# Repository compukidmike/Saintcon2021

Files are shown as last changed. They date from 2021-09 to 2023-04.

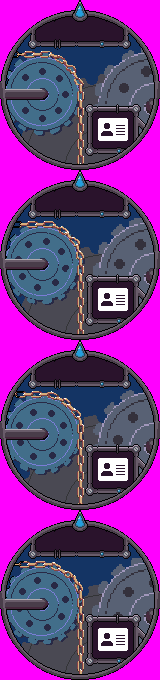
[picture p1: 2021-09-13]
Saintcon2021/ExternalFlash/menu.png

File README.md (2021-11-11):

# Saintcon2021

BadgeFrontUnlocked

This year's badge was created by compukidmike, Professor_Plum, and Sodium_Hydrogen. It's styled after a combination lock and the shackle actually opens!

BadgeFrontLocked

We tried something different for the front PCB. We used pcbbuy.com because they can do 2-color soldermask. It didn't turn out exactly like planned, but it was still a cool option that we'll probably use in the future.

One of the major features of the badge is NFC. The badge can read and write NFC tags, as well as emulate cards. This is used for sharing contact information, reading unlock tags, and trading items.

The main microcontroller is an ATSAME53J18A. The NFC controller is an ST25R95 and the LCD is actually round. The badge is composed of a stack of PCBs (4 boards thick, 5 boards total). Here's an exploded view of the badge:

Exploded
Inside

One of the big challenges was fitting parts under the screen. We've got the thickness of 2 boards (3.2mm) to fit everything. The LCD is 2.2mm thick, so that leaves 1mm for components. This made it extremely difficult to find parts, especially with the chip shortages this year.

## Firmware

### Compiling

You'll need to install ~~Atmel~~ Microchip Studio to compile the firmware. Once it's compiled, you can flash it to the badge with an SWD programmer, or follow the directions below to use the USB bootloader.

### Making a UF2 File

When you've compiled the firmware, Microchip Studio will create a bunch of files (likely in the Debug folder inside your project folder). You want the .hex file. You'll need to use a tool called uf2conv.py from https://github.com/microsoft/uf2 (it's in the utils folder). This python script will convert your hex file into a UF2 file that you can use to program your badge. Here's an example command: python .\uf2conv.py .\flash.bin -c -o .\flash.uf2

### Flashing

To re-flash your badge there is a USB bootloader. To activate it, move the power switch to USB and hold the button on the right side of the badge when you connect it to your computer. The screen should show some hardware tests and then it will connect to your computer as a mass storage device. Simply copy the new UF2 firmware file to the badge.

### External SPI Flash

The badge has an 8MB SPI flash chip that stores all the images. It can be reprogrammed via the bootloader, but it's a bit cumbersome. You'll need to use the makeFlash.py script in the ExternalFlash folder to create a binary file from the images. NOTE: The images will be placed in the binary one after the other aligned to 1024 byte boundaries. If you change the images, you'll need to update the list of image locations in flash.h

Once you've got the binary file, you need to convert it to a hex file. This can be done with with bin2hex.py script in the ExternalFlash folder. Here's an example command: python .\bin2hex.py .\flash.bin .\flash.hex

Finally, you need to convert this hex file into a UF2 file that the bootloader can use to reprogram the SPI flash. When using the uf2conv.py script, you'll need to add an offset parameter so that the bootloader knows this data is for the SPI flash. Here's an example command: python .\uf2conv.py .\flash.bin -c -b 0x4000000 -o .\flash.uf2

NOTE: When copying a UF2 file that reprograms the SPI flash, the badge will send an erase command to the SPI flash. This can take a while (30-60 seconds) and you will see an activity indicator on the screen. If this process takes too long, your computer may timeout on copying the file (the badge will change from "erasing" to "writing", but the LED will be pulsing slowly instead of blinking rapidly). If this happens, simply reset the badge into bootloader mode and copy the file again. This time the SPI flash will be empty and the erase command will be quick.

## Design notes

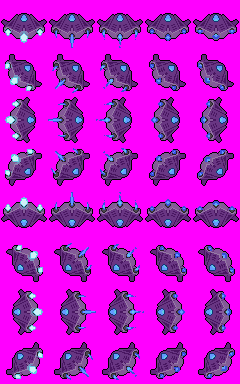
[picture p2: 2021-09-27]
Saintcon2021/ExternalFlash/ship.png

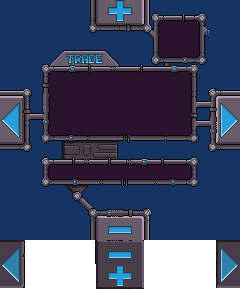
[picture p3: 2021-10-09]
Saintcon2021/ExternalFlash/trade.png

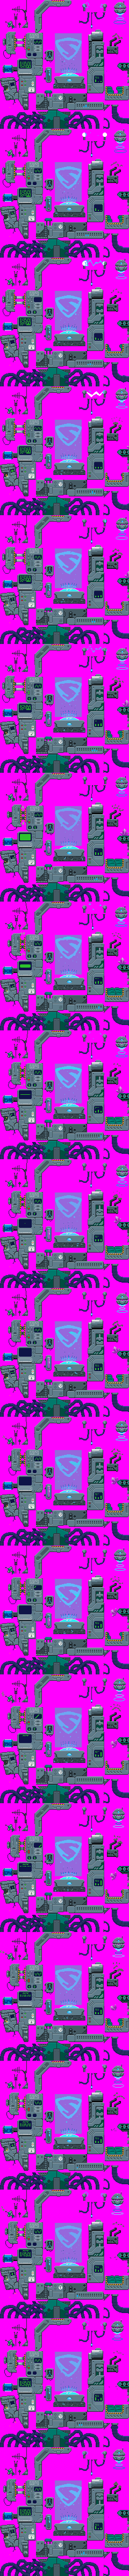
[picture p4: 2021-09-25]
Saintcon2021/ExternalFlash/machine.png

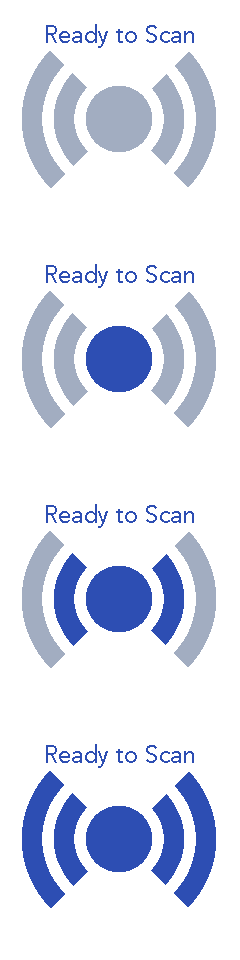
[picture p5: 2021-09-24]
Saintcon2021/ExternalFlash/nfc.png

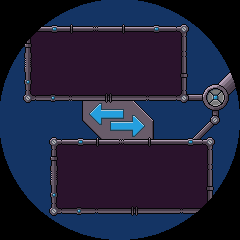
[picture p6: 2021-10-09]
Saintcon2021/ExternalFlash/trade2.png

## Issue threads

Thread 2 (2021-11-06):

Minibadge message collisions

kfeuz, 2021-11-06:
I have multiple hackers challenge minibadges which each have a little eeprom to store a message to be displayed by the main badge.  I changed the i2c address for each minibadge eeprom so that they don't collide and I can see each message start to be displayed.  However, each message clobber's the previous message as soon as it the code cycles to that address.  I propose adding a variable to track if the i2c address is displaying a message and if so wait for the appropriate delay before moving on to the next message. It looks like this was the plan all along but never got fully implemented (i.e. there is an if(true) statement right before checking the next minibadge address).  I can make the code change but I don't know how to build the code and how to flash the code after that.  Can you provide some guidance on that process or point me to the right resources to do so?

compukidmike, 2021-11-12:
Thanks for finding this bug and fixing the code!

Closed 2021-11-12.

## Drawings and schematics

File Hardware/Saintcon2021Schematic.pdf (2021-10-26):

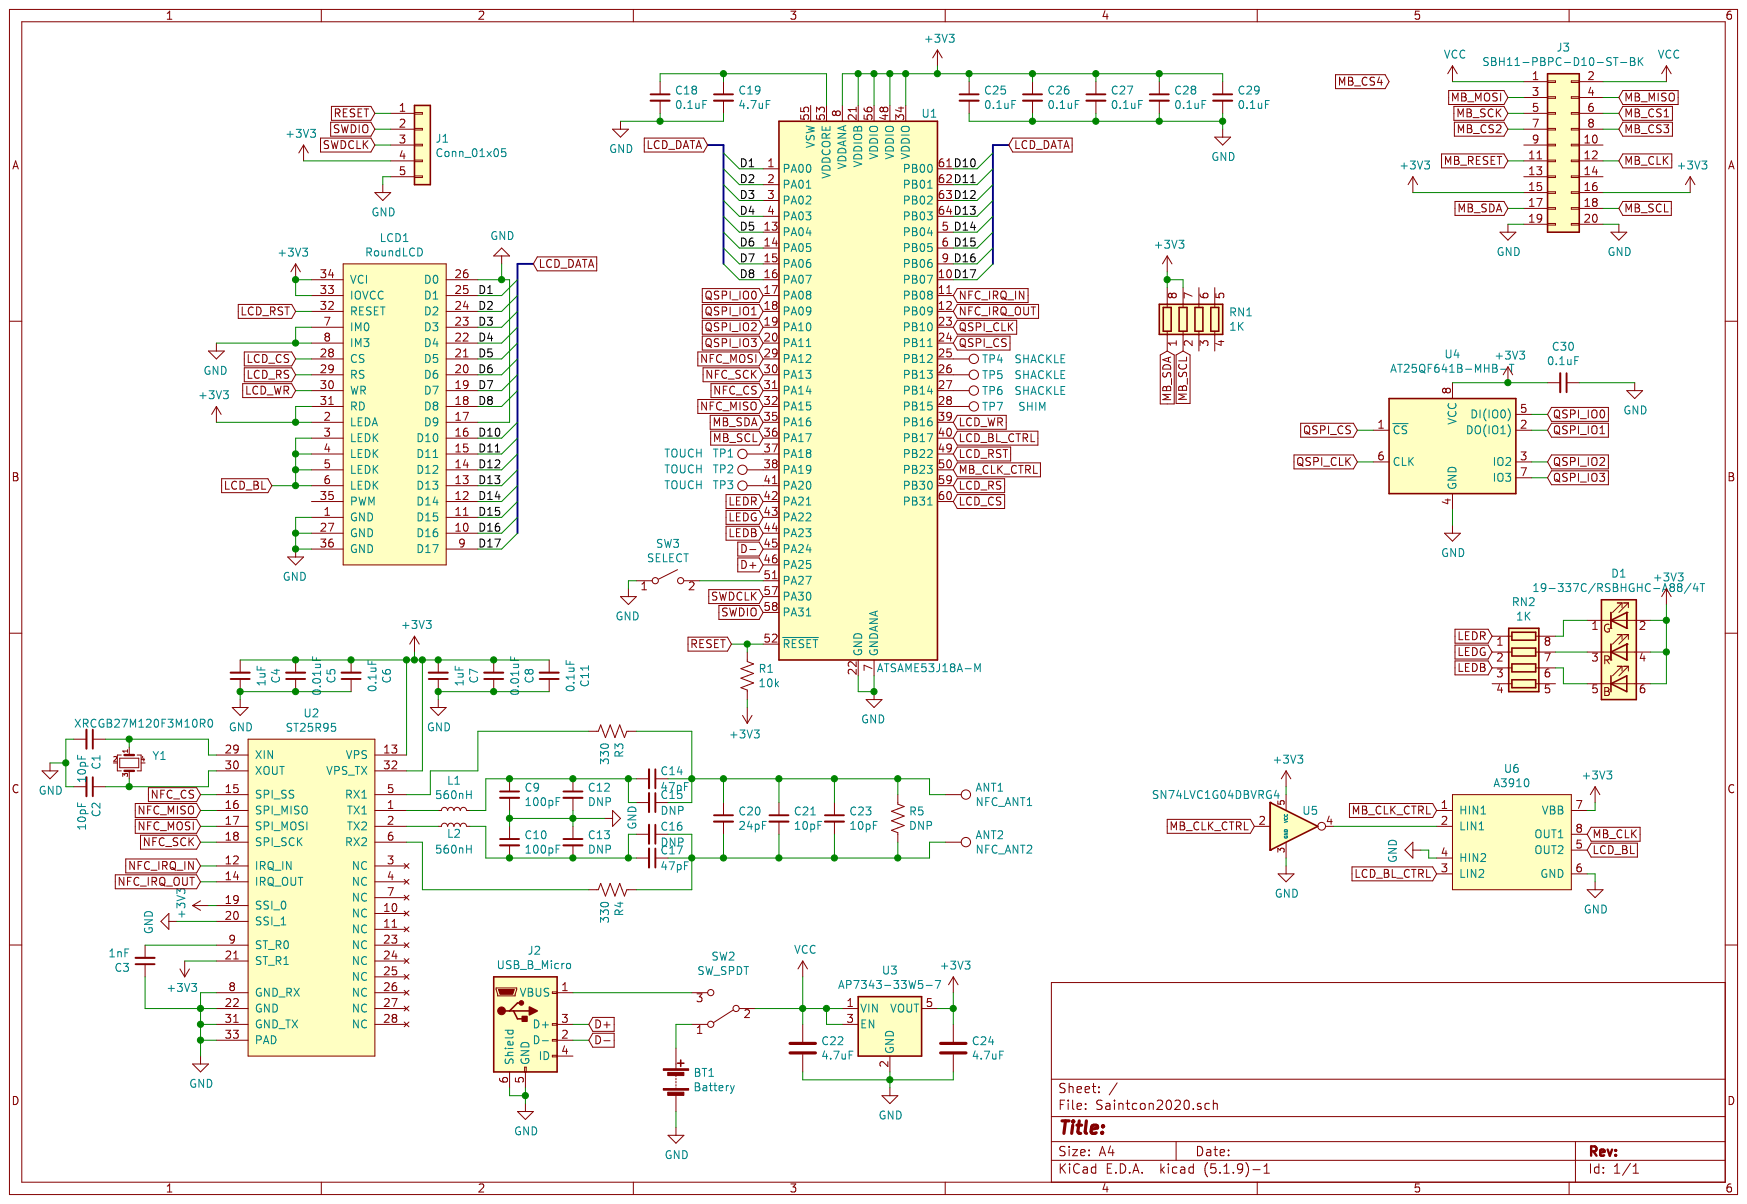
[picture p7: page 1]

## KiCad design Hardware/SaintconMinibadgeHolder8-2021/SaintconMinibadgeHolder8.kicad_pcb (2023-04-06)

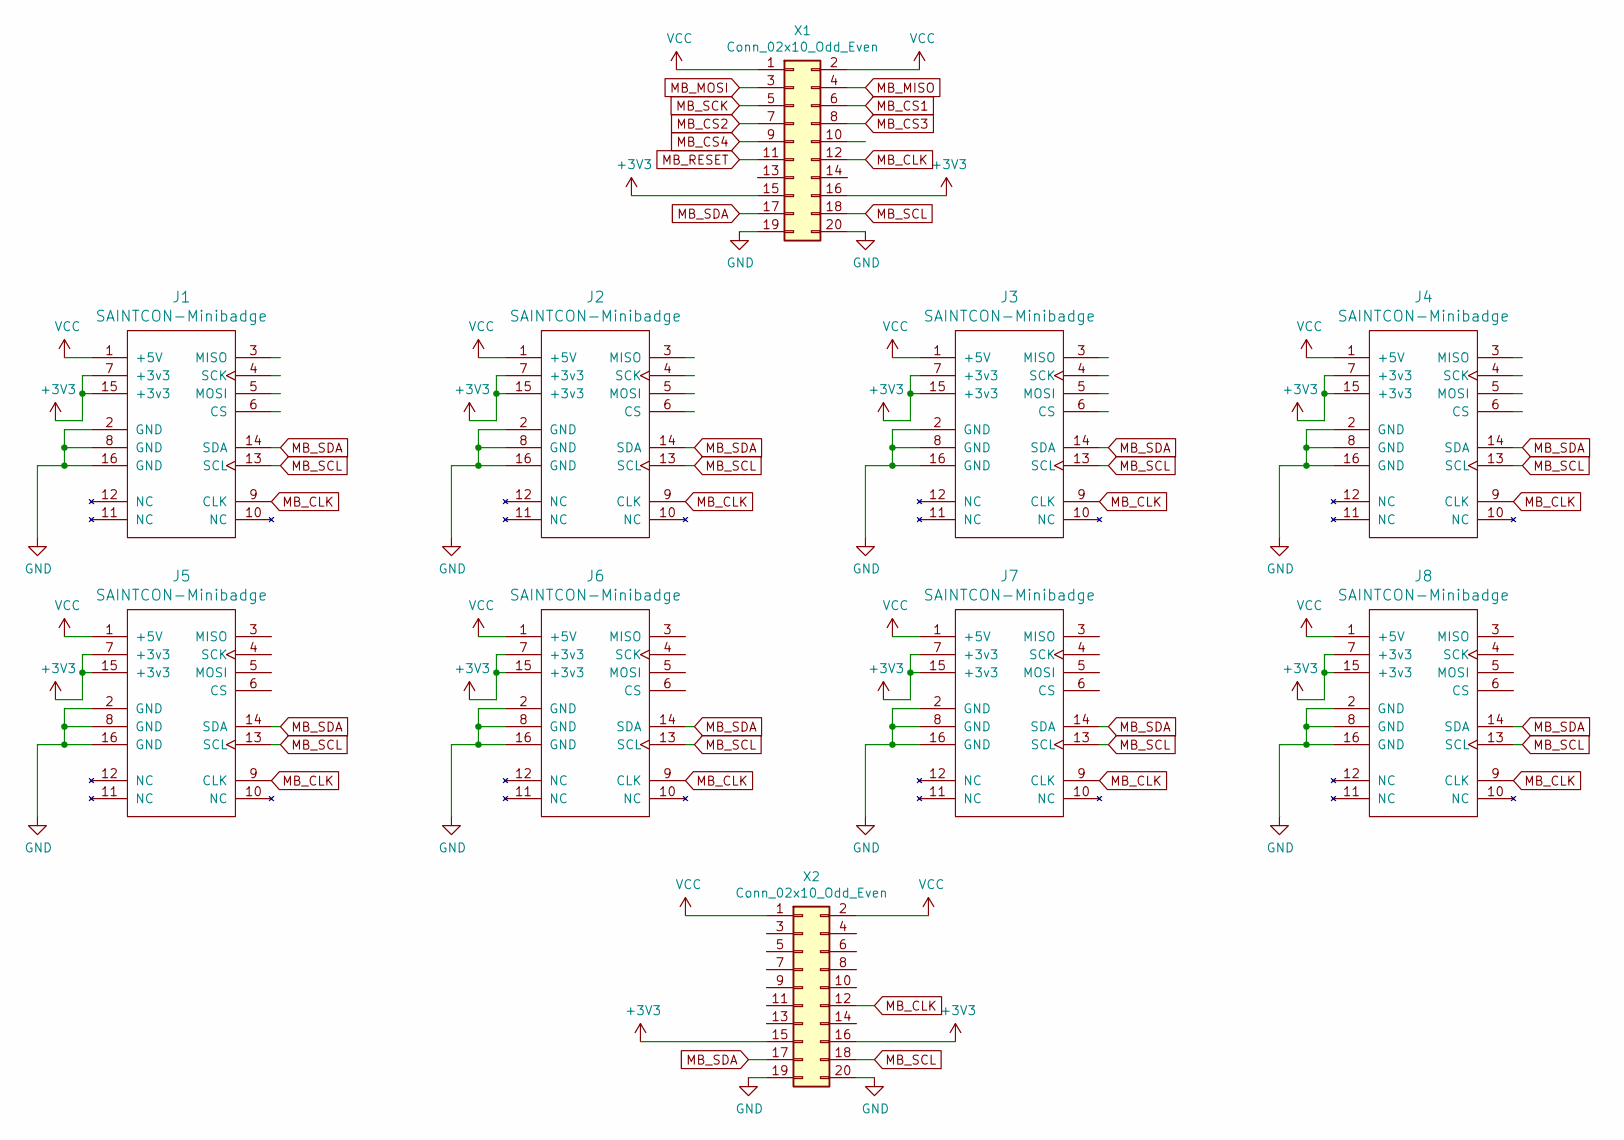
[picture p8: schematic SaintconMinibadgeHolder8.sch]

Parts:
J1, J2, J3, J4, J5, J6, J7, J8: SAINTCON-Minibadge; SAINTCON-Minibadge-Shiny
X1, X2: Conn_02x10_Odd_Even; Pin_Header_Straight_2x10_Pitch2.54mm

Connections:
+3V3: J1.7 (+3v3), J1.15 (+3v3), J2.7 (+3v3), J2.15 (+3v3), J3.7 (+3v3), J3.15 (+3v3), J4.7 (+3v3), J4.15 (+3v3), J5.7 (+3v3), J5.15 (+3v3), J6.7 (+3v3), J6.15 (+3v3), J7.7 (+3v3), J7.15 (+3v3), J8.7 (+3v3), J8.15 (+3v3), X1.15, X1.16, X2.15, X2.16
GND: J1.2 (GND), J1.8 (GND), J1.16 (GND), J2.2 (GND), J2.8 (GND), J2.16 (GND), J3.2 (GND), J3.8 (GND), J3.16 (GND), J4.2 (GND), J4.8 (GND), J4.16 (GND), J5.2 (GND), J5.8 (GND), J5.16 (GND), J6.2 (GND), J6.8 (GND), J6.16 (GND), J7.2 (GND), J7.8 (GND), J7.16 (GND), J8.2 (GND), J8.8 (GND), J8.16 (GND), X1.19, X1.20, X2.19, X2.20
MB_CLK: J1.9 (CLK), J2.9 (CLK), J3.9 (CLK), J4.9 (CLK), J5.9 (CLK), J6.9 (CLK), J7.9 (CLK), J8.9 (CLK), X1.12, X2.12
MB_CS1: X1.6
MB_CS2: X1.7
MB_CS3: X1.8
MB_CS4: X1.9
MB_MISO: X1.4
MB_MOSI: X1.3
MB_RESET: X1.11
MB_SCK: X1.5
MB_SCL: J1.13 (SCL), J2.13 (SCL), J3.13 (SCL), J4.13 (SCL), J5.13 (SCL), J6.13 (SCL), J7.13 (SCL), J8.13 (SCL), X1.18, X2.18
MB_SDA: J1.14 (SDA), J2.14 (SDA), J3.14 (SDA), J4.14 (SDA), J5.14 (SDA), J6.14 (SDA), J7.14 (SDA), J8.14 (SDA), X1.17, X2.17
VCC: J1.1 (+5V), J2.1 (+5V), J3.1 (+5V), J4.1 (+5V), J5.1 (+5V), J6.1 (+5V), J7.1 (+5V), J8.1 (+5V), X1.1, X1.2, X2.1, X2.2

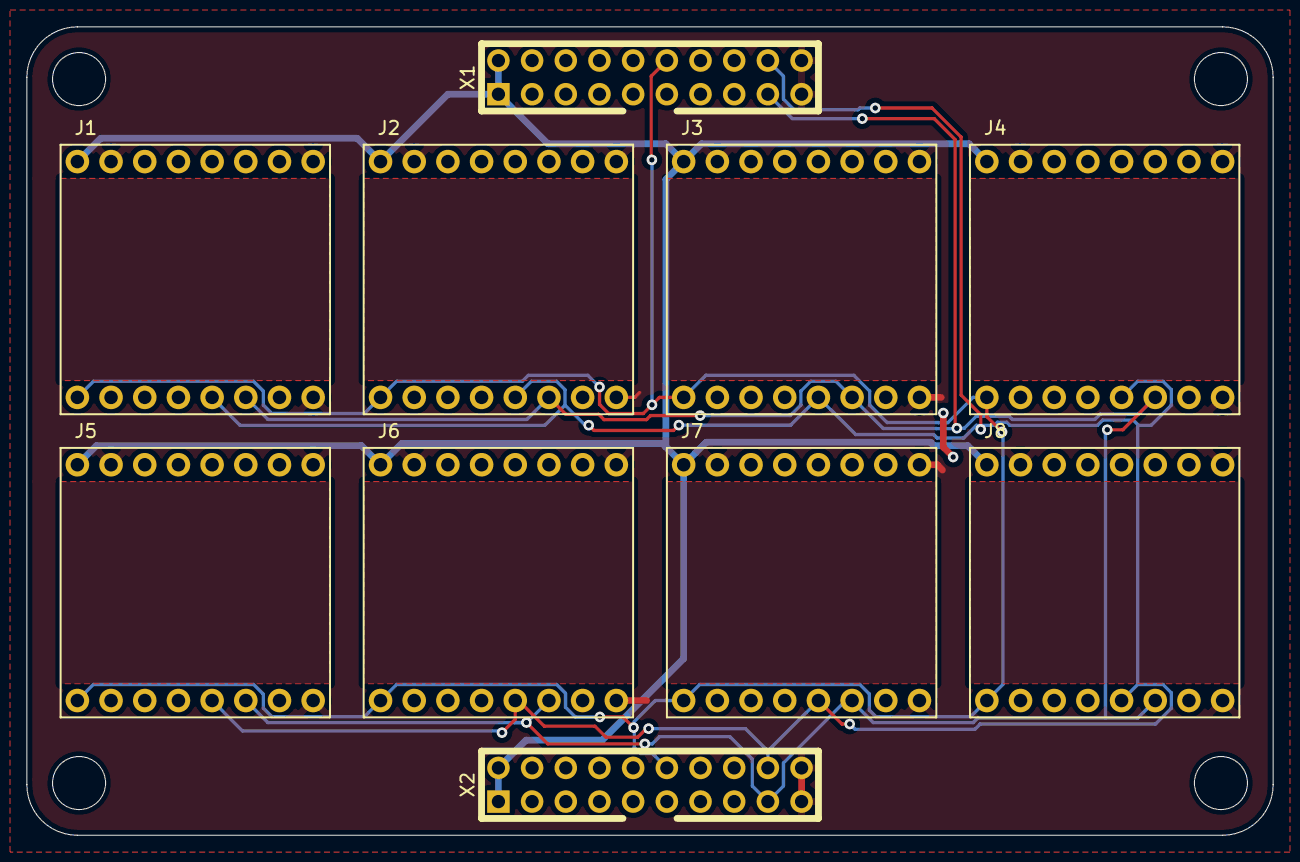
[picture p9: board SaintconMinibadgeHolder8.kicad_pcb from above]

Board: 2 copper layers, 94.0 x 61.0 mm, 11 parts (1 on the bottom side), 6 nets.

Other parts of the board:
Ref**: Val**; SaintconLogo2021

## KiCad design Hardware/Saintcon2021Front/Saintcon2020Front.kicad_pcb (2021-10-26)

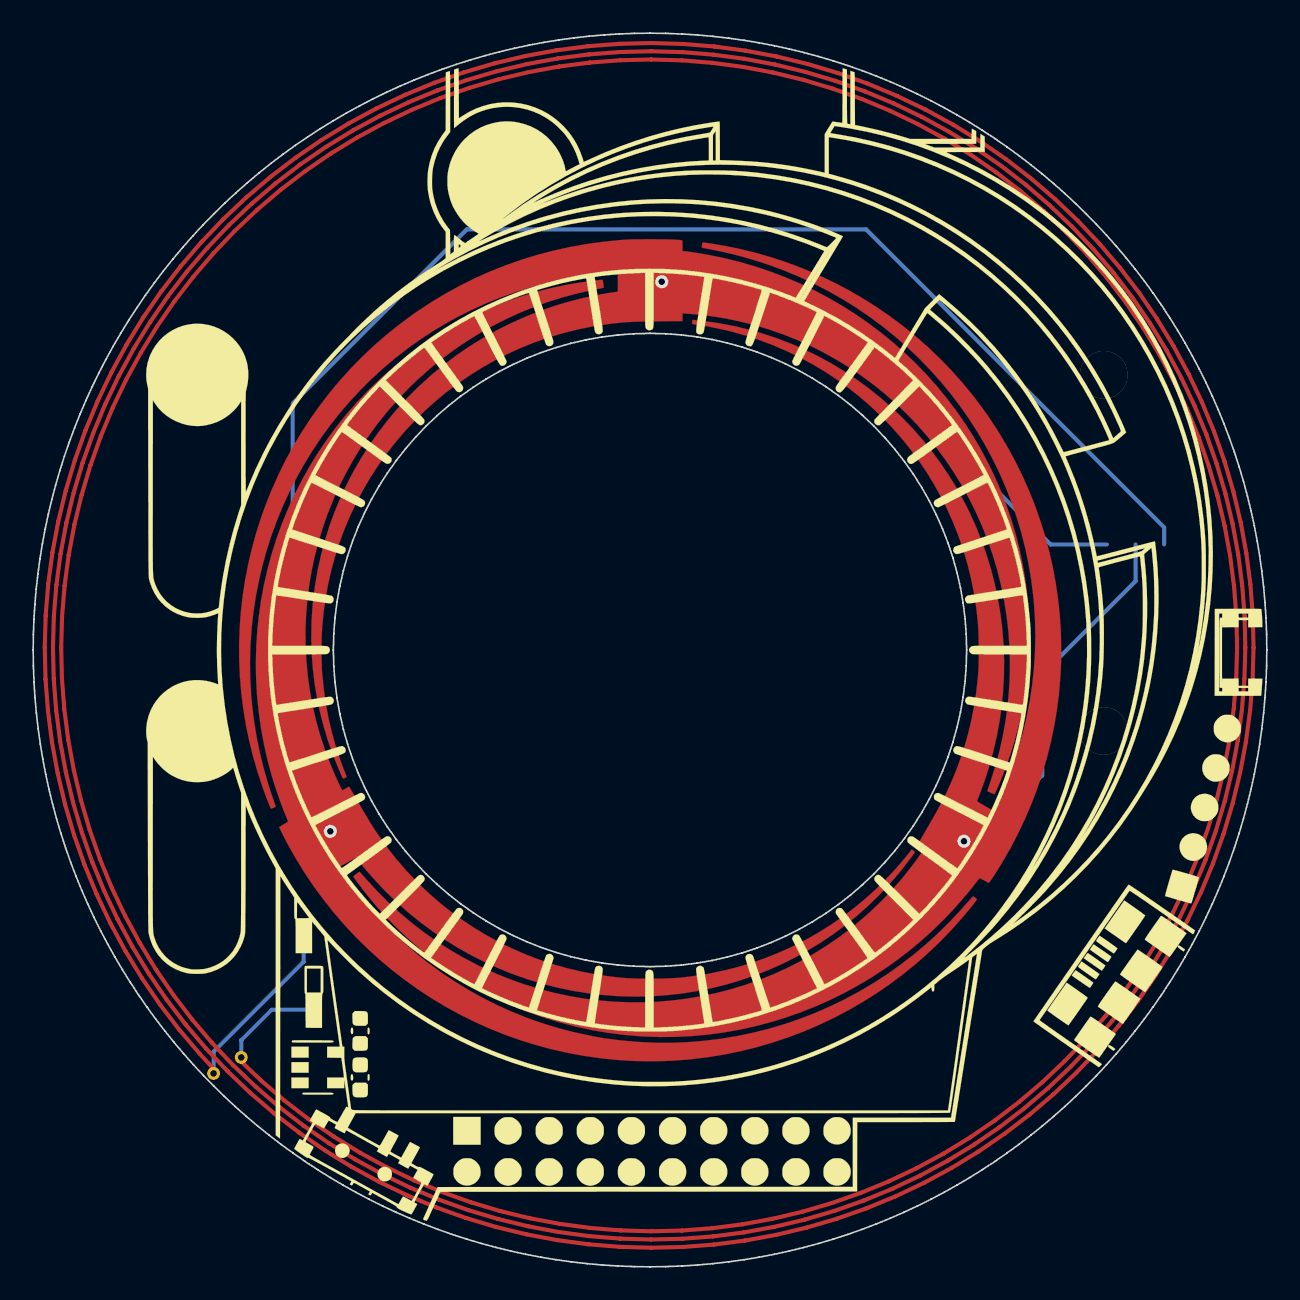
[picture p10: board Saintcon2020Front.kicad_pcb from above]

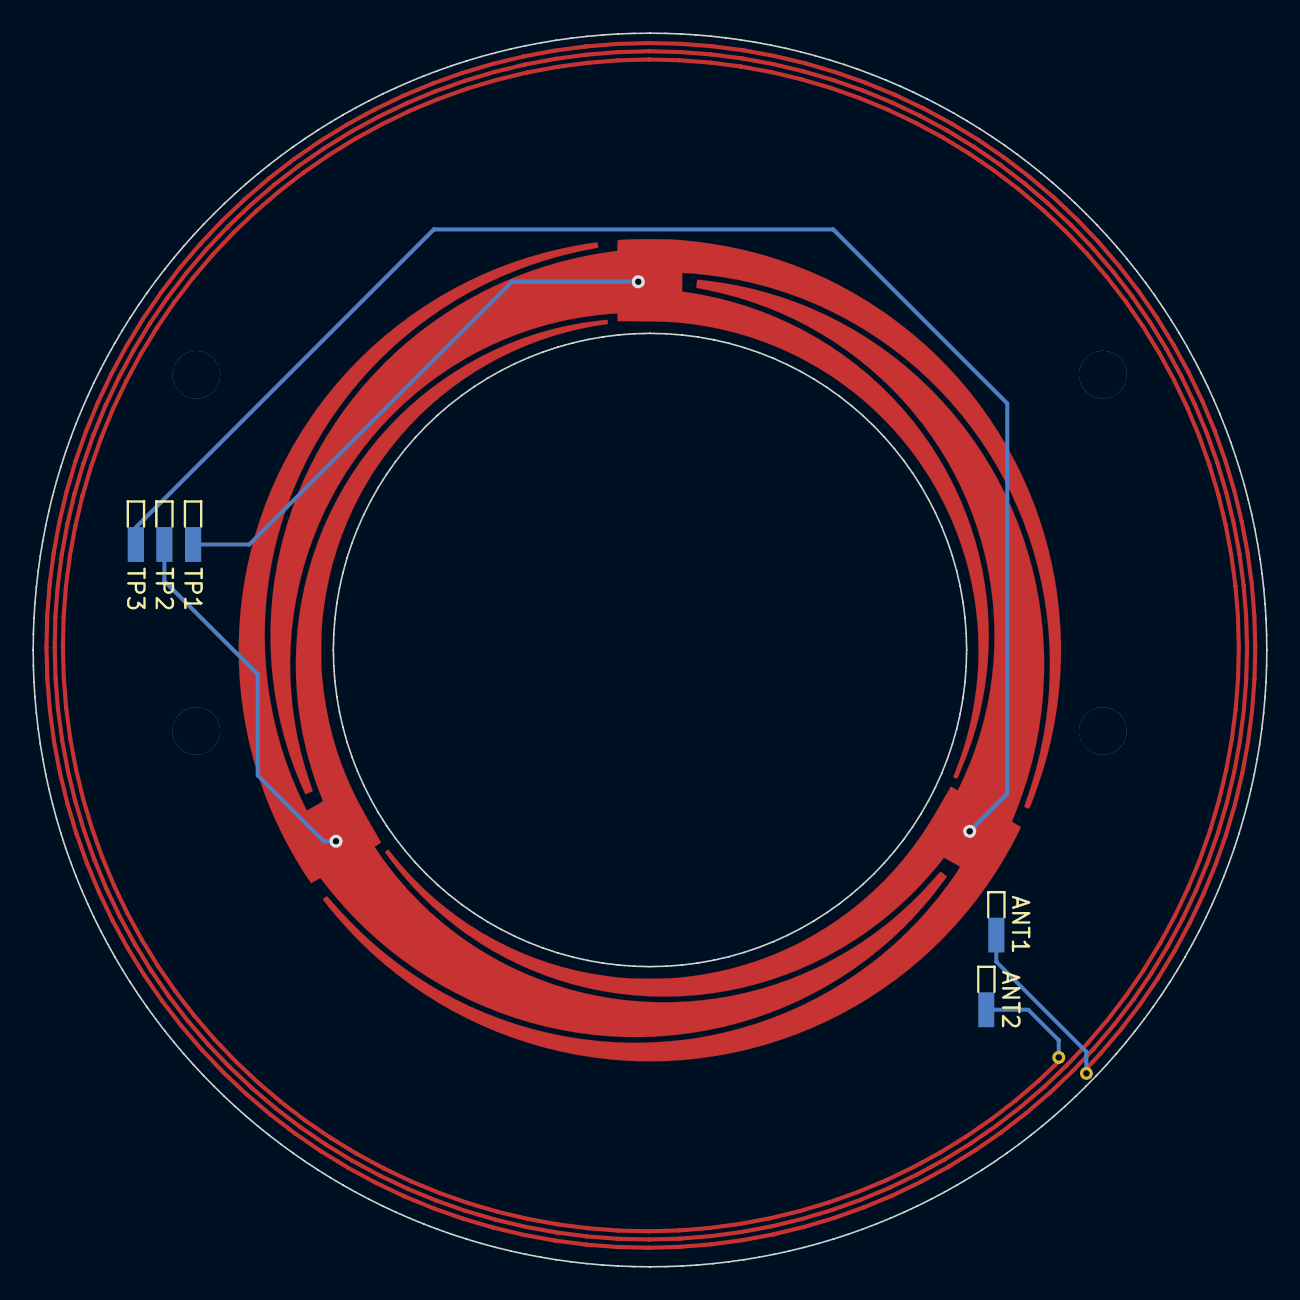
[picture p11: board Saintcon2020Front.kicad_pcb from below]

Board: 2 copper layers, 76.2 x 76.2 mm, 7 parts (5 on the bottom side), 2 nets.

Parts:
AE1: Antenna_Loop; SpiralAnt3_254000_508000
ANT1, ANT2: TestPoint; SPRING-120220-0315
Ref**: Val**; BoardFront3-Yellow
TP1, TP2, TP3: TestPoint; SPRING-120220-0315

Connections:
unnamed: AE1.1, ANT2.1
unnamed: AE1.2, ANT1.1

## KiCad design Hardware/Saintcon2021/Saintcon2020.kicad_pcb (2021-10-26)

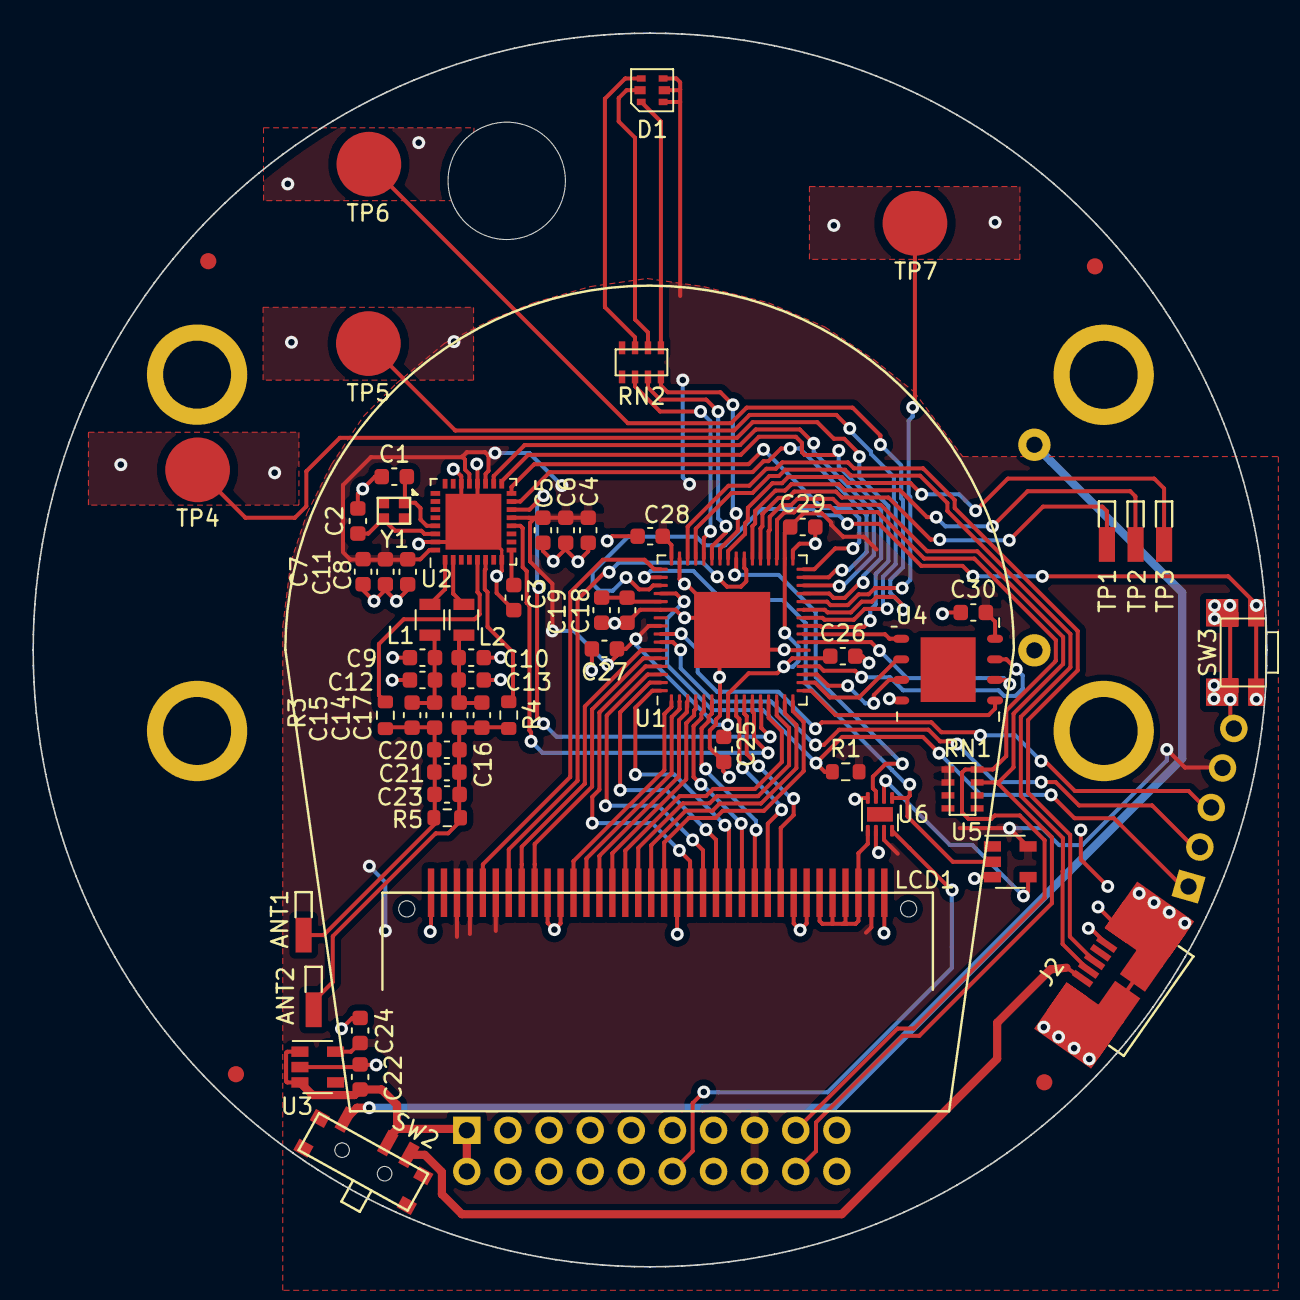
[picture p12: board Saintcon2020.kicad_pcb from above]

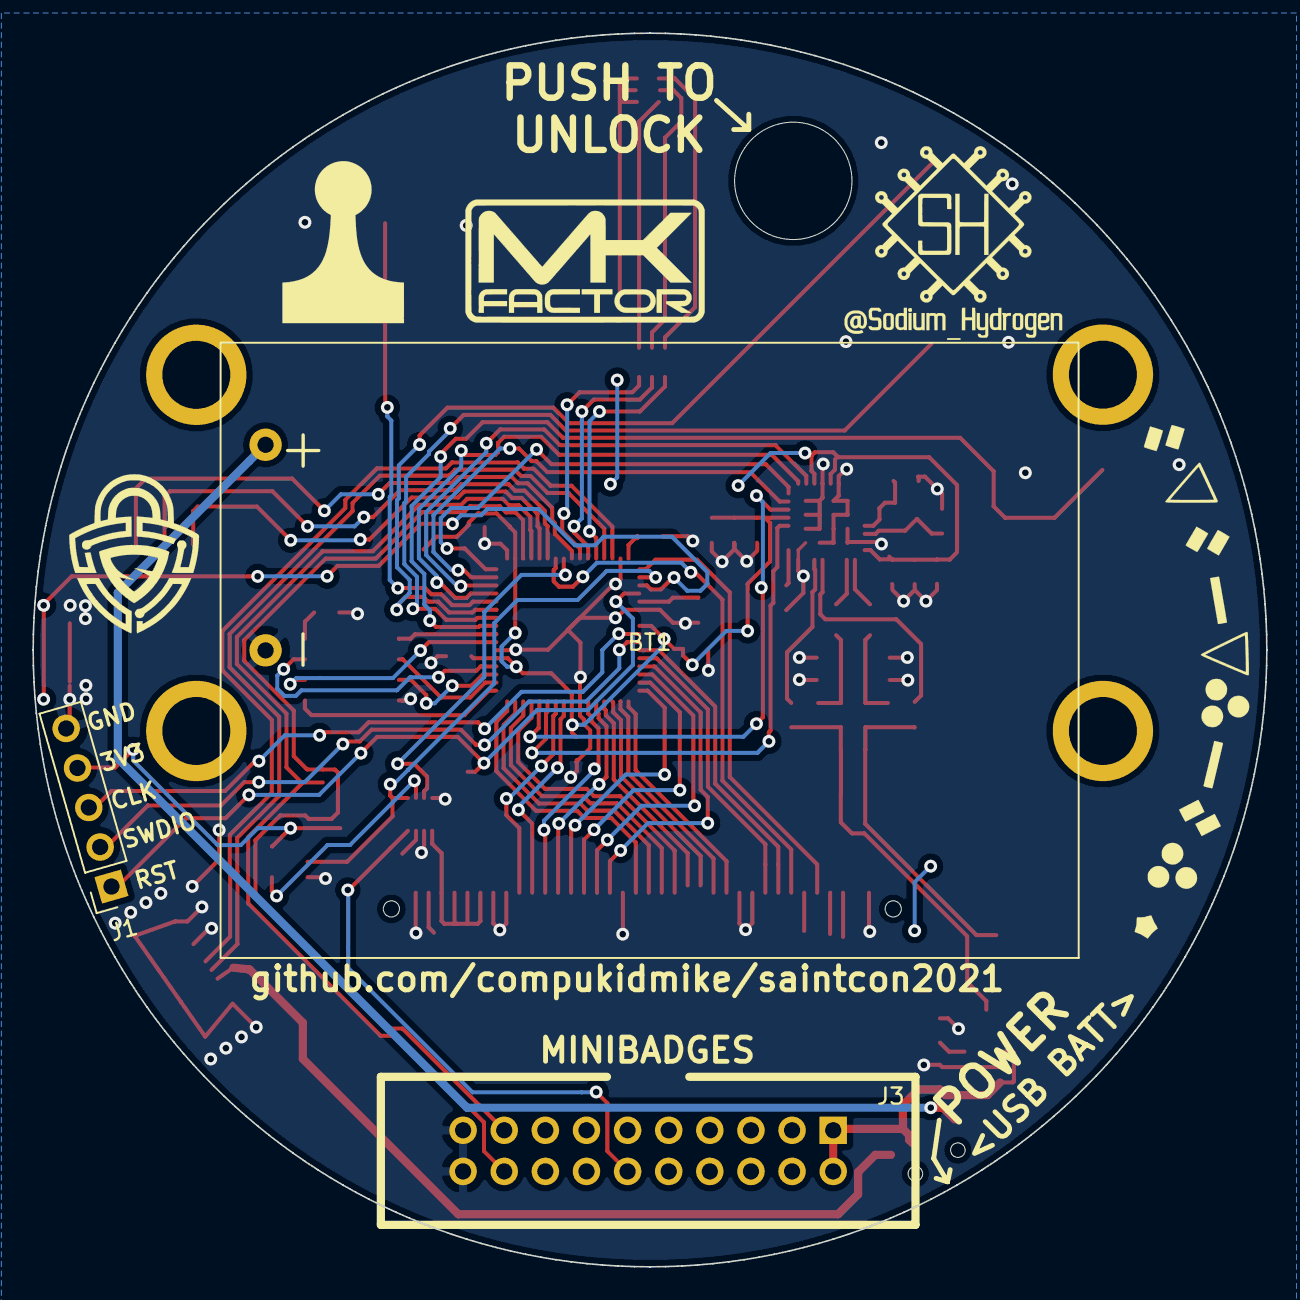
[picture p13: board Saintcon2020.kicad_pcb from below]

Board: 2 copper layers, 76.2 x 76.2 mm, 75 parts (6 on the bottom side), 75 nets.

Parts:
ANT1: NFC_ANT1; SPRING-120220-0315
ANT2: NFC_ANT2; SPRING-120220-0315
BT1: Battery; Battery3xAAA
C1, C2, C15, C16: 10pF; C_0603_1608Metric
C3: 1nF; C_0603_1608Metric
C4, C7: 1uF; C_0603_1608Metric
C5, C8: 0.01uF; C_0603_1608Metric
C6, C11, C18, C25, C26, C27, C28, C29, C30: 0.1uF; C_0603_1608Metric
C9, C10, C12, C13: 100pF; C_0603_1608Metric
C14, C17: 47pF; C_0603_1608Metric
C19, C22, C24: 4.7uF; C_0603_1608Metric
C20: 24pF; C_0603_1608Metric
C21, C23: DNP; C_0603_1608Metric
D1: 19-337C/RSBHGHC-A88/4T; 19-337C_RSBHGHC-A88_4T
FID1, FID2, FID3, FID4: Fiducial_1mm_Mask2mm
J1: Conn_01x05; PinSocket_1x05_P2.54mm_Vertical
J2: USB_B_Micro; 10118192-0002LF
J3: SBH11-PBPC-D10-ST-BK; Pin_Header_Straight_2x10_Pitch2.54mm
L1, L2: 560nH; L_0805
LCD1: RoundLCD; RoundLCD-36P
R1: 10k; R_0603_1608Metric
R3, R4: 330; R_0603_1608Metric
R5: DNP; R_0603_1608Metric
RN1, RN2: 1K; RAVF164D-RES_PACK_4
Ref**: Val**; SodiumHydrogen_logo
Ref**#2: Val**; SaintconLogo2021
Ref**#3: Val**; BackSilkCombo
Ref**#4: Val**; ProfessorPlum_logo
Ref**#5: Val**; BoardShape
STANDOFF1, STANDOFF2, STANDOFF3, STANDOFF4: Standoff-4-40
SW2: SW_SPDT; CUS-12B
SW3: SELECT; KMS231GFLS
TP1, TP2, TP3: TOUCH; SPRING-120220-0315
TP4, TP5, TP6: SHACKLE; TouchButton4mm
TP7: SHIM; TouchButton4mm
U1: ATSAME53J18A-M; QFN-64-1EP_9x9mm_P0.5mm_EP4.7x4.7mm
U2: ST25R95
U3: NCP115ASN330T2G; SOT-23-5
U4: AT25QF641B-MHB-T; UDFN-8_EP_6x5_Pitch1.27mm
U5: SN74LVC1G04DBVRG4; SOT-23-5
U6: A3910; DFN-8-1EP_2x2mm_P0.5mm_EP0.9x1.6mm
Y1: XRCGB27M120F3M10R0; Crystal-XRCGB27M120F3M10R0

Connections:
+3V3: C4.2, C5.2, C6.2, C7.2, C8.2, C11.2, C24.1, C25.1, C26.1, C27.1, C28.1, C29.1, C30.2, D1.2, D1.4, D1.6, J1.4, J3.15, J3.16, LCD1.2, LCD1.31, LCD1.33, LCD1.34, R1.2, RN1.7, RN1.8, U1.8, U1.21, U1.34, U1.48, U1.56, U2.13, U2.19, U2.21, U2.32, U3.5, U4.8, U5.5, U6.7
/D1: LCD1.25, U1.1
/D2: LCD1.24, U1.2
/D3: LCD1.23, U1.3
/D4: LCD1.22, U1.4
/D5: LCD1.21, U1.13
/D6: LCD1.20, U1.14
/D7: LCD1.19, U1.15
/D8: LCD1.18, U1.16
/D10: LCD1.16, U1.61
/D11: LCD1.15, U1.62
/D12: LCD1.14, U1.63
/D13: LCD1.13, U1.64
/D14: LCD1.12, U1.5
/D15: LCD1.11, U1.6
/D16: LCD1.10, U1.9
/D17: LCD1.9, U1.10
D+: J2.3, U1.46
D-: J2.2, U1.45
GND: BT1.2, C1.2, C2.2, C3.1, C4.1, C5.1, C6.1, C7.1, C8.1, C9.2, C10.1, C11.1, C12.2, C13.1, C18.2, C19.2, C22.2, C24.2, C25.2, C26.2, C27.2, C28.2, C29.2, C30.1, J1.5, J2.5, J2.6, J3.19, J3.20, LCD1.1, LCD1.7, LCD1.8, LCD1.17, LCD1.26, LCD1.27, LCD1.36, SW3.1, U1.7, U1.22, U1.33, U1.47, U1.54, U1.65, U2.8, U2.20, U2.22, U2.31, U2.33, U3.2, U4.4, U5.3, U6.4, U6.6
LCD_BL: LCD1.3, LCD1.4, LCD1.5, LCD1.6, U6.5
LCD_BL_CTRL: U1.40, U6.3
LCD_CS: LCD1.28, U1.60
LCD_RS: LCD1.29, U1.59
LCD_RST: LCD1.32, U1.49
LCD_WR: LCD1.30, U1.39
LEDB: RN2.3, U1.44
LEDG: RN2.2, U1.43
LEDR: RN2.1, U1.42
MB_CLK: J3.12, U6.8
MB_CLK_CTRL: U1.50, U5.2, U6.1
MB_SCL: J3.18, RN1.2, U1.36
MB_SDA: J3.17, RN1.1, U1.35
NFC_CS: U1.31, U2.15
NFC_IRQ_IN: U1.11, U2.12
NFC_IRQ_OUT: U1.12, U2.14
NFC_MISO: U1.32, U2.16
NFC_MOSI: U1.29, U2.17
NFC_SCK: U1.30, U2.18
unnamed: ANT1.1, C14.1, C15.1, C20.1, C21.1, C23.1, R3.1, R5.1
unnamed: ANT2.1, C16.1, C17.1, C20.2, C21.2, C23.2, R4.1, R5.2
unnamed: BT1.1, SW2.1
unnamed: C1.1, U2.29, Y1.1
unnamed: C2.1, U2.30, Y1.3
unnamed: C3.2, U2.9
unnamed: C10.2, C13.2, C16.2, C17.2, L2.2
unnamed: C9.1, C12.1, C14.2, C15.2, L1.2
unnamed: C18.1, C19.1, U1.53
unnamed: D1.1, RN2.8
unnamed: D1.3, RN2.7
unnamed: D1.5, RN2.6
unnamed: J2.1, SW2.3
unnamed: L1.1, U2.1
unnamed: L2.1, U2.2
unnamed: R3.2, U2.5
unnamed: R4.2, U2.6
unnamed: SW3.2, U1.51
unnamed: TP1.1, U1.37
unnamed: TP2.1, U1.38
unnamed: TP3.1, U1.41
unnamed: TP4.1, U1.25
unnamed: TP5.1, U1.26
unnamed: TP6.1, U1.27
unnamed: TP7.1, U1.28
unnamed: U5.4, U6.2
QSPI_CLK: U1.23, U4.6
QSPI_CS: U1.24, U4.1
QSPI_IO0: U1.17, U4.5
QSPI_IO1: U1.18, U4.2
QSPI_IO2: U1.19, U4.3
QSPI_IO3: U1.20, U4.7
RESET: J1.1, R1.1, U1.52
SWDCLK: J1.3, U1.57
SWDIO: J1.2, U1.58
VCC: C22.1, J3.1, J3.2, SW2.2, U3.1, U3.3

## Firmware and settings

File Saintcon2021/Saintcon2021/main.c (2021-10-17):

#include "main.h"
#include "ILI9331.h"
#include <math.h>
#include <string.h>
#include <stdio.h>
#include "nfc.h"
#include <stdlib.h>
#include "hal_sleep.h"

volatile uint8_t measurement_done_touch;
uint8_t  scroller_status   = 0;
uint16_t scroller_position = 0;
uint8_t key_status = 0;
uint8_t keys[4] = {0};
badgestate g_state;

bool back_event = false;
bool unlock_event = false;
bool claspopen = false;
bool rouge_event = false;

#include "FrameBuffer.h"
#include "flash.h"
#include "eeprom.h"
#include "machine_common.h"

extern uint16_t bird_raw[];
extern uint32_t minibadge_delay;

static void back_button_pressed(void);
static struct timer_task Timer_task1;

#define MB_CLK_DELAY 500

const uint8_t touch_lut[256] = {
	0, 0, 0, 0, 0, 1, 1, 1, 2, 2, 3, 3, 4, 4, 5, 6, 7, 8, 9, 10, 11, 12, 13, 14, 15, 16, 18, 19, 20, 21, 23,
	24, 26, 27, 29, 30, 32, 33, 35, 36, 38, 39, 41, 43, 44, 46, 47, 49, 50, 52, 53, 55, 56, 58, 59, 61, 62,
	64, 65, 66, 68, 69, 70, 71, 72, 74, 75, 76, 77, 78, 78, 79, 80, 81, 81, 82, 83, 83, 84, 84, 84, 85, 85,
	85, 85, 85, 85, 85, 85, 85, 86, 86, 86, 87, 87, 88, 88, 89, 89, 90, 91, 92, 93, 94, 95, 96, 97, 98, 99,
	100, 101, 103, 104, 105, 106, 108, 109, 111, 112, 114, 115, 117, 118, 120, 121, 123, 124, 126, 128, 129,
	131, 132, 134, 135, 137, 138, 140, 141, 143, 144, 146, 147, 149, 150, 151, 153, 154, 155, 156, 157, 159,
	160, 161, 162, 163, 163, 164, 165, 166, 166, 167, 168, 168, 169, 169, 169, 170, 170, 170, 170, 170, 170,
	170, 170, 170, 171, 171, 171, 172, 172, 173, 173, 174, 174, 175, 176, 177, 178, 179, 180, 181, 182, 183,
	184, 185, 186, 188, 189, 190, 191, 193, 194, 196, 197, 199, 200, 202, 203, 205, 206, 208, 209, 211, 213,
	214, 216, 217, 219, 220, 222, 223, 225, 226, 228, 229, 231, 232, 234, 235, 236, 238, 239, 240, 241, 242,
	244, 245, 246, 247, 248, 248, 249, 250, 251, 251, 252, 253, 253, 254, 254, 254, 255, 255, 255, 255, 255
};
#define JAIL_DEVICE

static void Timer_task1_cb(const struct timer_task *const timer_task)
{
	touch_process();
}

void Timer_touch_init(void)
{
	Timer_task1.interval = 20;
	Timer_task1.cb       = Timer_task1_cb;
	Timer_task1.mode     = TIMER_TASK_REPEAT;

	timer_add_task(&Timer, &Timer_task1);
	timer_start(&Timer);
}

void vcard_write_callback(char* vcarddata) {
	const char* magic = "PRODID:-//saintcon_2021_magic";
	size_t mlen = strlen(magic) +1;
	size_t vlen = strlen(vcarddata);
	char* dp = strstr(vcarddata, magic);
	if (dp) {
		vlen -= dp-vcarddata;
		vlen -= mlen;
		memmove(dp, dp+mlen, vlen+1);
		dp[strlen(dp)-1]='\0';
		flash_save_vcard(vcarddata);
		uint8_t cc[] = {255,255,255};
		led_set_color(cc);
		NVIC_SystemReset();
	}
}

void nfc_write_cb() {
	uint8_t lc[256];
	memcpy(lc, TAG_BUFF, 256);
	ndef_header *ndef = (ndef_header*)lc;
	if (strncmp(&lc[0x15], "text/vcard", 10) == 0) { //Lazy hacks!
		vcard_write_callback(&lc[0x15+10]);
	}
	else if (strncmp(&lc[0x15], "application/encrypted", 21)==0){
		nfc_trade_write_callback(&lc[0x15+21]);
	}
}

int main(void)
{
	char vcard[512];
	/* Initializes MCU, drivers and middleware */
	atmel_start_init();
	SysTick_Config(48000000/1000);

	/* Replace with your application code */
	pwm_enable(&PWM_0);
	pwm_set_parameters(&PWM_0,255,100);
	
	
	gpio_set_pin_direction(PIN_PB17,GPIO_DIRECTION_OUT);
	gpio_set_pin_level(PIN_PB17,true);
	
	rand_sync_enable(&RAND_0);
	LCD_Init();
	
	eeprom_init();
	eeprom_load_state();

	
	flash_init();
	uint8_t id[4];
	flash_read_id(id);
	
	spi_m_sync_get_io_descriptor(&SPI_1, &io);

	spi_m_sync_enable(&SPI_1);
	
	nfc_init();
	uint8_t cc[] = {0, 255, 0};
	if(!nfc_test()){
		cc[0] = 255;
		cc[1] = 0;
	}
	led_set_color(cc);
	//End NFC Test
	uint8_t ndef_data[] = {NDEF_URL, URL_HTTPS, 's','a','i','n','t','c','o','n','2','0','2','1','.','s','c','h','e','d','.','c','o','m'};
	ndef_well_known(ndef_data, sizeof(ndef_data));
	start_nfc_tag_emulation(true, nfc_write_cb);	
	
	ext_irq_register(PIN_PA27, back_button_pressed);
	Timer_touch_init();
	
	Scene scene = MENU;
	bool changed = true;
	bool lastclasp = false;
	bool screenon = true;
	uint32_t lastTouch = millis();
	uint32_t lastMinibadgeClk = 0;
	
#ifdef JAIL_DEVICE
	if (!flash_has_vard()) {
		scene = TEST;
	}
#endif
	
	
	gpio_set_pin_direction(MB_CLK_PIN, GPIO_DIRECTION_OUT);
	gpio_set_pin_level(MB_CLK_PIN, false);
	
	minibagde_holder_init();
	while (1) {
		
		unlock_event = false;
		
		key_status = get_sensor_state(3) & KEY_TOUCHED_MASK;
		if (0u != key_status) {
			// LED_ON
			keys[0] = 1;
			} else {
			// LED_OFF
			keys[0] = 0;
		}
		key_status = get_sensor_state(4) & KEY_TOUCHED_MASK;
		if (0u != key_status) {
			// LED_ON
			keys[1] = 1;
			} else {
			// LED_OFF
			keys[1] = 0;
		}
		key_status = get_sensor_state(5) & KEY_TOUCHED_MASK;
		if (0u != key_status) {
			// LED_ON
			keys[2] = 1;
			} else {
			// LED_OFF
			keys[2] = 0;
		}
		key_status = get_sensor_state(6) & KEY_TOUCHED_MASK;
		if (0u != key_status) {
			// LED_ON
			keys[3] = 1;
			} else {
			// LED_OFF
			keys[3] = 0;
		}
		
		if (keys[0] && !keys[1] && keys[2]) {
			claspopen = true;
			if (lastclasp == false)
				unlock_event = true;
			lastclasp = true;
		}
		else if (!keys[0] && keys[1] && !keys[2]) {
			claspopen = false;
			lastclasp = false;
		}
		
		if (keys[3]){
			if(newUnlock(UNLOCK_SHIM)) {
				scene = REWARD;
				changed = true;
			} else {
				//Already unlocked
				static bool shim_message = false;
				if(shim_message == false){ //Only show this once per power cycle, in case the sensor gets messed up
					setMessage("Shim already unlocked");
					scene = MESSAGE;
					changed = true;
				}
				shim_message = true;
			}
		}
		
		uint32_t now = millis();
		if (rouge_event && newUnlock(UNLOCK_ROUGE)) {
			scene = REWARD;
			changed = true;
			if (!screenon) {
				LCD_Wake();
				screenon = true;
			}
			lastTouch = now;
		}
		
		if((now - lastMinibadgeClk)>MB_CLK_DELAY){
			lastMinibadgeClk = now;
			gpio_toggle_pin_level(MB_CLK_PIN);
		}
		

		scroller_status   = get_scroller_state(0);
		//scroller_position = get_scroller_position(0);
		scroller_position = touch_lut[get_scroller_position(0)];
		
		if (scroller_status) {
			if (!screenon) {
				LCD_Wake();
				screenon = true;
			}
			lastTouch = now;
		}
		
		if (now > (lastTouch + SCREEN_OFF_AFTER)) {
			if (screenon) {
				LCD_Sleep();
				led_off();
				screenon = false;
				//sleep(4); //Standby Mode
			}			
		}
		
		Scene ns;
		switch(scene) {
		case TEST:
			ns = test_scene_loop(changed);
			break;
		case COMBO:
			ns = combo_scene_loop(changed);
			break;
		case INVENTORY:
			ns = inventory_scene_loop(changed);
			break;
		case MACHINE:
			ns = machine_scene_loop(changed);
			break;
		case BUILD:
			ns = build_scene_loop(changed);
			break;
		case REWARD:
			ns = reward_scene_loop(changed);
			break;
		case MESSAGE:
			ns = message_scene_loop(changed);
			break;
		case NFCREADER:
			ns = nfc_scene_loop(changed);
			break;
		case GAME:
			ns = game_scene_loop(changed);
			break;
		case TRADING:
			ns = trade_scene_loop(changed);
			break;
		case RICK:
			ns = rick_scene_loop(changed);
			break;
		case MENU:
		default:
			ns = menu_scene_loop(changed);
		}
		changed = false;
		
		if (ns != scene) {
			changed = true;
			scene = ns;
		}
		
		cdcd_loop();
	}
}

/** \brief Do SPI read in polling way
 *  For SPI master, activate CS, do send 0xFFs and read data, deactivate CS.
 *
 *  It blocks until all data read or error.
 *
 *  \param[in, out] spi Pointer to the HAL SPI instance.
 *  \param[out] buf Pointer to the buffer to store read data.
 *  \param[in] size Size of the data in number of characters.
 *  \return Operation status.
 *  \retval size Success.
 *  \retval >=0 Time out, with number of characters read.
 */
int32_t spi_m_sync_io_readwrite(struct io_descriptor *io, uint8_t *rxbuf, uint8_t *txbuf, const uint16_t length)
{
	ASSERT(io);

	struct spi_m_sync_descriptor *spi = CONTAINER_OF(io, struct spi_m_sync_descriptor, io);
	struct spi_xfer               xfer;

	xfer.rxbuf = rxbuf;
	xfer.txbuf = txbuf;
	xfer.size  = length;

	return spi_m_sync_transfer(spi, &xfer);
}

static void back_button_pressed(void)
{
	back_event = true;
}

volatile uint32_t MS_Timer = 0;
void SysTick_Handler(void) {
	MS_Timer++;                // Increment global millisecond timer
}

uint32_t millis() {
	return MS_Timer;
}


int getTouchLocation() {
	int ret = scroller_position*360/256 + 270;
	if (ret > 360) ret-=360;
	return ret;
}

void led_set_color(uint8_t color[3]){
	hri_tcc_write_CC_reg(TCC0, 2, 255-color[0]);
	hri_tcc_write_CC_reg(TCC0, 1, 255-color[1]);
	hri_tcc_write_CC_reg(TCC0, 3, 255-color[2]);
}

void led_off(void){
	hri_tcc_write_CC_reg(TCC0, 2, 255);
	hri_tcc_write_CC_reg(TCC0, 1, 255);
	hri_tcc_write_CC_reg(TCC0, 3, 255);
}


bool newUnlock(uint16_t unlockflag) {
	if (g_state.badge_bitmask & unlockflag)
	return false;
	g_state.badge_bitmask |= unlockflag;
	return true;
}

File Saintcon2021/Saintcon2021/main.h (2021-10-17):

/*
 * main.h
 */ 


#ifndef MAIN_H_
#define MAIN_H_

#define MB_CLK_PIN PIN_PB23

#define SCREEN_OFF_AFTER	1000 * 60

#include <atmel_start.h>
#include <stdint.h>

struct io_descriptor *io;
#include <stdint.h>
#include <atmel_start.h>

#define LED_COLOR_OFF (uint8_t[]){0,0,0}
#define LED_COLOR_RED (uint8_t[]){255,0,0}
#define LED_COLOR_GREEN (uint8_t[]){0,255,0}
#define LED_COLOR_BLUE (uint8_t[]){0,0,255}
#define LED_COLOR_YELLOW (uint8_t[]){127,127,0}
#define LED_COLOR_WHITE (uint8_t[]){85,85,85}

typedef enum {
	MENU,
	BUILD,
	TRADING,
	COMBO,
	GAME,
	MACHINE,
	INVENTORY,
	NFCREADER,
	REWARD,
	MESSAGE,
	TEST,
	RICK
} Scene;

#define REWARD_SHIM			(1<<0)
#define REWARD_GAME1		(1<<1)
#define REWARD_GAME2		(1<<2)
#define REWARD_MINIBADGE	(1<<3)
#define REWARD_VENDOR		(1<<4)
#define REWARD_HC			(1<<5)
#define REWARD_TRADE		(1<<6)

//NOTE: if you modify this update the eeprom save/load functions
typedef struct _badgestate {
	uint32_t modules_bitmask;
	uint32_t combos_bitmask;
	uint32_t nfc_bitmask;
	uint32_t badge_bitmask;
	uint8_t part_count[12];
} badgestate;

extern bool back_event, unlock_event, claspopen; 
extern badgestate g_state;
extern uint8_t  scroller_status;
extern uint16_t scroller_position;
extern bool rouge_event;

void touch_status_display(void);
int getTouchLocation(void);
uint32_t millis();
void nfc_write_cb();

int32_t spi_m_sync_io_readwrite(struct io_descriptor *io, uint8_t *rxbuf, uint8_t *txbuf, const uint16_t length);

//void NFC_init(void);
void exampleRfalPollerRun( void );
void exampleNFCARun( void );
Scene test_scene_loop(bool init);
Scene menu_scene_loop(bool init);
Scene combo_scene_loop(bool init);
Scene inventory_scene_loop(bool init);
Scene machine_scene_loop(bool init);
Scene build_scene_loop(bool init);
Scene reward_scene_loop(bool init);
Scene message_scene_loop(bool init);
Scene nfc_scene_loop(bool init);
Scene game_scene_loop(bool init);
Scene trade_scene_loop(bool init);
Scene rick_scene_loop(bool init);

int isValidCombo(uint8_t l1, uint8_t l2, uint8_t l3);
void setMessage(const char* msg);
void minibagde_holder_init();

void led_set_color(uint8_t color[3]);
void led_off(void);

bool newUnlock(uint16_t unlockflag);
#endif /* MAIN_H_ */

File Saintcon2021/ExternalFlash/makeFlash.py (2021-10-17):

#! /usr/bin/env python3

from PIL import Image
import struct, os, sys

##
if __name__ == '__main__':
    with open('flash.bin', 'wb') as outf:
        for filename in ['sclogo.png', 'machine_bkg.png', 'machine.png', 'build.png', 'parts.png', 'menu.png', 'crate.png', 
            'nfc.png', 'ball.png', 'inventory.png', 'ship.png', 'explode.png', 'trade.png', 'trade2.png', 'whammy.png', 'rick.png']:
            if os.path.exists(filename) == False: 
                error('not exists: ' + filename)
            body, _ = os.path.splitext(filename)

            img = Image.open(filename).convert('RGB')
            pixels = list(img.getdata())
            count =0

            print("#define %-20s \t ((uint32_t)0X%06X)"%(body.upper()+"_IMG", outf.tell()))

            for pix in pixels:
                r = (pix[0] >> 3) & 0x1F
                g = (pix[1] >> 2) & 0x3F
                b = (pix[2] >> 3) & 0x1F
                outf.write(struct.pack('H', (r << 11) + (g << 5) + b))
                count += 2

            while (outf.tell() %1024):
                outf.write(b'\xFF')

        outf.write(b'\0'*118)
        outf.write(b'Lock Combo: 38-8-18 ')
        outf.write(b'\0'*118)
        print()
        print("%dKB used"%(outf.tell()/1024))

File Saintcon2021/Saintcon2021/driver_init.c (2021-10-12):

/*
 * Code generated from Atmel Start.
 *
 * This file will be overwritten when reconfiguring your Atmel Start project.
 * Please copy examples or other code you want to keep to a separate file
 * to avoid losing it when reconfiguring.
 */

#include "driver_init.h"
#include <peripheral_clk_config.h>
#include <utils.h>
#include <hal_init.h>

#include <hpl_rtc_base.h>

struct aes_sync_descriptor   CRYPTOGRAPHY_0;
struct sha_sync_descriptor   HASH_ALGORITHM_0;
struct timer_descriptor      Timer;
struct spi_m_sync_descriptor SPI_1;

struct qspi_sync_descriptor QUAD_SPI_0;

struct i2c_m_sync_desc I2C_0;

struct pwm_descriptor PWM_0;

struct rand_sync_desc RAND_0;

/**
 * \brief PTC initialization function
 *
 * Enables PTC peripheral, clocks and initializes PTC driver
 */
static void PTC_0_clock_init(void)
{
	hri_mclk_set_APBDMASK_ADC0_bit(MCLK);
	hri_gclk_write_PCHCTRL_reg(GCLK, ADC0_GCLK_ID, CONF_GCLK_ADC0_SRC | (1 << GCLK_PCHCTRL_CHEN_Pos));
}

/**
 * \brief AES initialization function
 *
 * Enables AES peripheral, clocks and initializes AES driver
 */
void CRYPTOGRAPHY_0_init(void)
{
	hri_mclk_set_APBCMASK_AES_bit(MCLK);
	aes_sync_init(&CRYPTOGRAPHY_0, AES);
}

void EXTERNAL_IRQ_0_init(void)
{
	hri_gclk_write_PCHCTRL_reg(GCLK, EIC_GCLK_ID, CONF_GCLK_EIC_SRC | (1 << GCLK_PCHCTRL_CHEN_Pos));
	hri_mclk_set_APBAMASK_EIC_bit(MCLK);

	// Set pin direction to input
	gpio_set_pin_direction(PB09, GPIO_DIRECTION_IN);

	gpio_set_pin_pull_mode(PB09,
	                       // <y> Pull configuration
	                       // <id> pad_pull_config
	                       // <GPIO_PULL_OFF"> Off
	                       // <GPIO_PULL_UP"> Pull-up
	                       // <GPIO_PULL_DOWN"> Pull-down
	                       GPIO_PULL_UP);

	gpio_set_pin_function(PB09, PINMUX_PB09A_EIC_EXTINT9);

	// Set pin direction to input
	gpio_set_pin_direction(PA27, GPIO_DIRECTION_IN);

	gpio_set_pin_pull_mode(PA27,
	                       // <y> Pull configuration
	                       // <id> pad_pull_config
	                       // <GPIO_PULL_OFF"> Off
	                       // <GPIO_PULL_UP"> Pull-up
	                       // <GPIO_PULL_DOWN"> Pull-down
	                       GPIO_PULL_UP);

	gpio_set_pin_function(PA27, PINMUX_PA27A_EIC_EXTINT11);

	ext_irq_init();
}

void HASH_ALGORITHM_0_CLOCK_init(void)
{
	hri_mclk_set_AHBMASK_ICM_bit(MCLK);
	hri_mclk_set_APBCMASK_ICM_bit(MCLK);
}

/**
 * \brief SHA initialization function
 *
 * Enables SHA peripheral, clocks and initializes SHA driver
 */
void HASH_ALGORITHM_0_init(void)
{
	HASH_ALGORITHM_0_CLOCK_init();
	sha_sync_init(&HASH_ALGORITHM_0, ICM);
}

void QUAD_SPI_0_PORT_init(void)
{

	// Set pin direction to input
	gpio_set_pin_direction(PB11, GPIO_DIRECTION_IN);

	gpio_set_pin_pull_mode(PB11,
	                       // <y> Pull configuration
	                       // <id> pad_pull_config
	                       // <GPIO_PULL_OFF"> Off
	                       // <GPIO_PULL_UP"> Pull-up
	                       // <GPIO_PULL_DOWN"> Pull-down
	                       GPIO_PULL_OFF);

	gpio_set_pin_function(PB11, PINMUX_PB11H_QSPI_CS);

	gpio_set_pin_direction(PA08,
	                       // <y> Pin direction
	                       // <id> pad_direction
	                       // <GPIO_DIRECTION_OFF"> Off
	                       // <GPIO_DIRECTION_IN"> In
	                       // <GPIO_DIRECTION_OUT"> Out
	                       GPIO_DIRECTION_OUT);

	gpio_set_pin_level(PA08,
	                   // <y> Initial level
	                   // <id> pad_initial_level
	                   // <false"> Low
	                   // <true"> High
	                   false);

	gpio_set_pin_pull_mode(PA08,
	                       // <y> Pull configuration
	                       // <id> pad_pull_config
	                       // <GPIO_PULL_OFF"> Off
	                       // <GPIO_PULL_UP"> Pull-up
	                       // <GPIO_PULL_DOWN"> Pull-down
	                       GPIO_PULL_OFF);

	gpio_set_pin_function(PA08,
	                      // <y> Pin function
	                      // <id> pad_function
	                      // <i> Auto : use driver pinmux if signal is imported by driver, else turn off function
	                      // <PINMUX_PA08H_QSPI_DATA0"> Auto
	                      // <GPIO_PIN_FUNCTION_OFF"> Off
	                      // <GPIO_PIN_FUNCTION_A"> A
	                      // <GPIO_PIN_FUNCTION_B"> B
	                      // <GPIO_PIN_FUNCTION_C"> C
	                      // <GPIO_PIN_FUNCTION_D"> D
	                      // <GPIO_PIN_FUNCTION_E"> E
	                      // <GPIO_PIN_FUNCTION_F"> F
	                      // <GPIO_PIN_FUNCTION_G"> G
	                      // <GPIO_PIN_FUNCTION_H"> H
	                      // <GPIO_PIN_FUNCTION_I"> I
	                      // <GPIO_PIN_FUNCTION_J"> J
	                      // <GPIO_PIN_FUNCTION_K"> K
	                      // <GPIO_PIN_FUNCTION_L"> L
	                      // <GPIO_PIN_FUNCTION_M"> M
	                      // <GPIO_PIN_FUNCTION_N"> N
	                      PINMUX_PA08H_QSPI_DATA0);

	gpio_set_pin_direction(PA09,
	                       // <y> Pin direction
	                       // <id> pad_direction
	                       // <GPIO_DIRECTION_OFF"> Off
	                       // <GPIO_DIRECTION_IN"> In
	                       // <GPIO_DIRECTION_OUT"> Out
	                       GPIO_DIRECTION_OUT);

	gpio_set_pin_level(PA09,
	                   // <y> Initial level
	                   // <id> pad_initial_level
	                   // <false"> Low
	                   // <true"> High
	                   false);

	gpio_set_pin_pull_mode(PA09,
	                       // <y> Pull configuration
	                       // <id> pad_pull_config
	                       // <GPIO_PULL_OFF"> Off
	                       // <GPIO_PULL_UP"> Pull-up
	                       // <GPIO_PULL_DOWN"> Pull-down
	                       GPIO_PULL_OFF);
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

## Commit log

2021-08-17 Added Basic LCD driver (still needs DMA), added some files to ignore list
2021-08-18 Added FrameBuffer
2021-08-19 Add Touch Wheel
2021-08-19 Fix abs implicit declaration with proper include
    [ILI9331.c, main.c]
2021-08-20 Add EEPROM emulator driver
2021-08-23 User interface work, depends on flash image, milis timer, and other features not done yet
2021-08-24 Changed button to use interrupts
2021-08-26 Added USB CDC driver
2021-08-30 Moved touch_process to timer interrupt for better responsiveness
2021-09-05 NFC and millis fixes
    fix merge issues and fix millis adding when returning value.
    [main.c]
2021-09-05 Fix LED PWM driver
    [main.c, main.h]
2021-09-10 Updated Flash driver for new chip
2021-09-11 Add touch buttons for shackle
2021-09-11 Fix touch button code
    [main.c]
2021-09-13 Change touch wheel calibration
2021-09-14 NFC fixes
    Ignore field errors and wait for valid frame.
2021-09-18 Change USB Vendor ID
    Using the default Atmel vendor ID causes the IDE to think it's a dev board which makes debugging slow.
2021-09-19 Turn off display when not in use to save power
2021-10-05 Fix off by 1 error with page addressing
    [nfc.c]
2021-10-13 Added missing files, eeprom fix, and more functions in prep for nfc ssupport
    [main.c]
2021-10-15 Fixed Badge crash with NFC IRQ
    [nfc.c]
2021-10-15 Fix read timings to match ntag2xx standars (5ms max)
    [nfc.c]
2021-10-15 Fix Touch Wheel Linearity
    [board_config.h, main.c]
2021-10-16 Fix tag emu bug, Clasp dect bug, enable jail
    [main.c, main.h, menuScene.c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]
2021-10-16 Fixed cheating guards in rouge game
    [gameScene.c]
2021-10-16 Added more lights, fixed nfc tag rewards bug
    [main.c, menuScene.c]
2021-10-16 Minor bugs fixes and improvments
    [gameScene.c, main.c]
2021-10-16 Fix flash partial erase
    [main.c]
2021-10-17 Add Minibadge CLK, fix NFC unlocks, fix bootloader available size, replace bird image with saintcon logo
    [main.c, main.h, makeFlash.py]
2021-10-18 Fix off by one error
    [nfc.c]
2021-10-26 Add Hardware files (schematic, kicad files, etc)
    [Saintcon2020.kicad_pcb, Saintcon2020.sch, Saintcon2020Front.kicad_pcb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]
2021-11-12 Fixed minibadge message collision
    [menuScene.c]
2023-04-06 Add minibadge holder board
    [SaintconMinibadgeHolder8.kicad_pcb, SaintconMinibadgeHolder8.sch]
